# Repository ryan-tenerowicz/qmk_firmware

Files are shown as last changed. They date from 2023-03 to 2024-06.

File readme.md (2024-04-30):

# Lynxware Cat with trackpoint

https://www.lynxware.org/

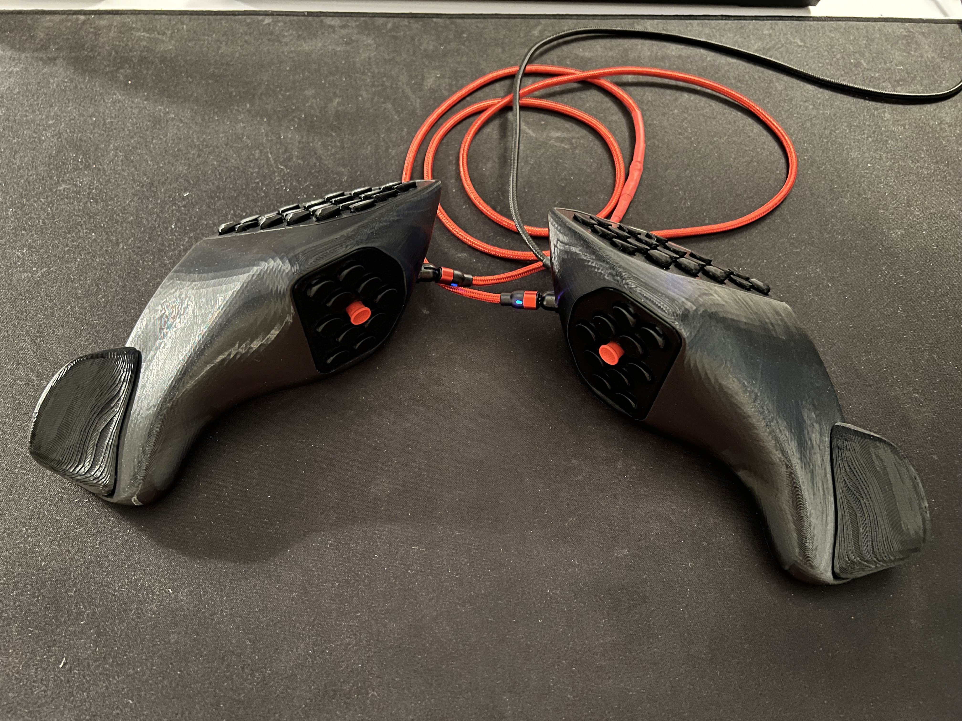
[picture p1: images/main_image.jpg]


I made some modifications to the case to work with the hardware I have. I already had some dual trackpoint code working in QMK so I made the connection wired and setup the matrix for qmk. I really like the magnetic usb cables so I carved out enough room for them. 

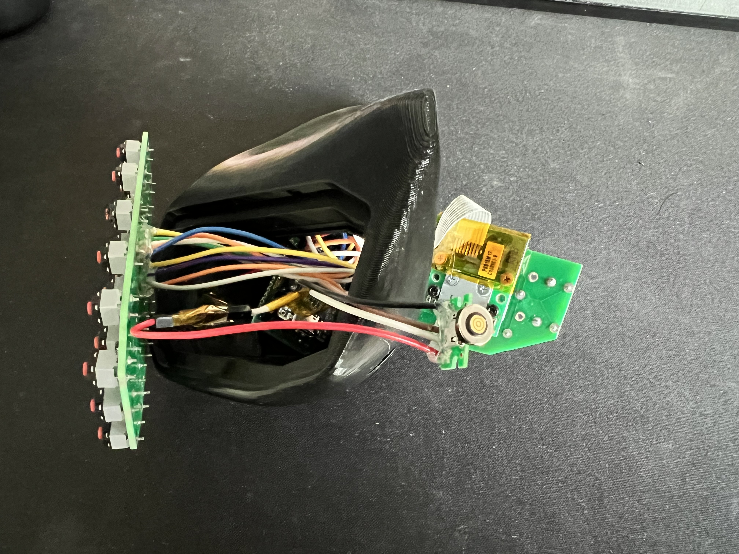
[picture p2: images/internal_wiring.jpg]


There's plenty of room on the inside so I was able to fit the reset circut easily.

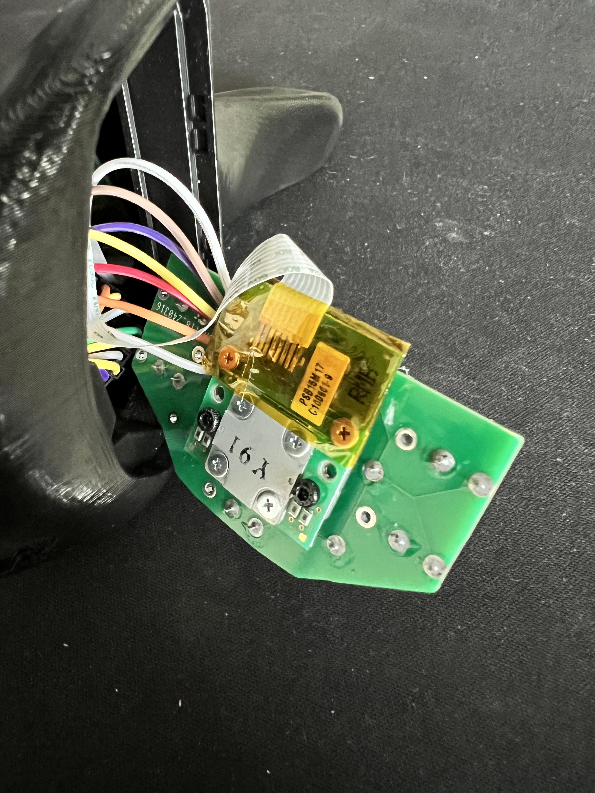
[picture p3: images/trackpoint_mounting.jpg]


I was able to get a much better surface finish on the keys by printing them at an angle. And I added wings to them to keep them from falling outwards because I was using smaller silent mouse switches.

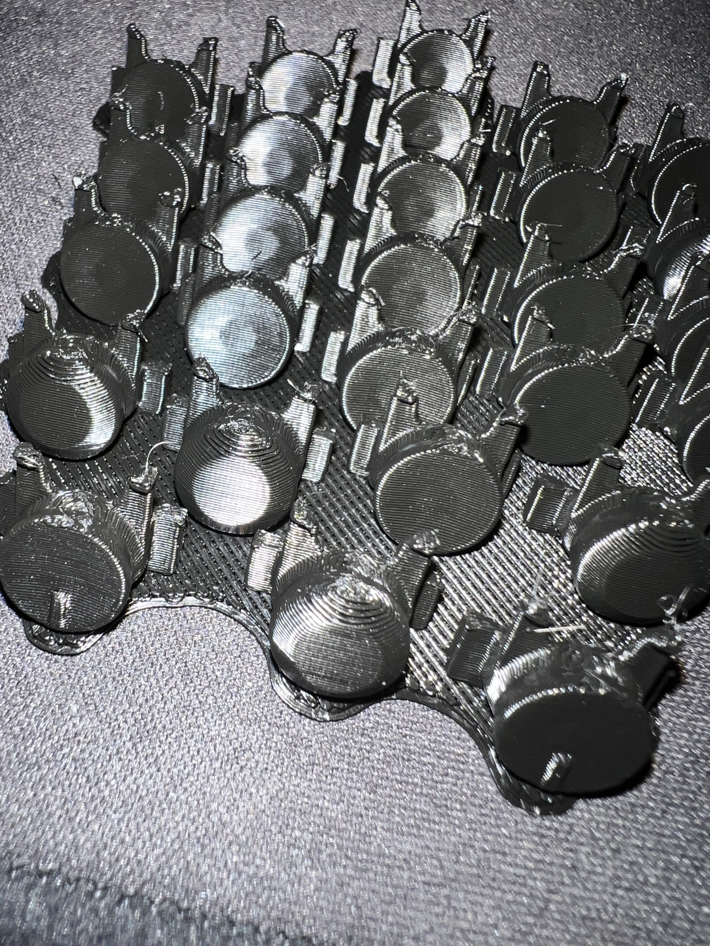
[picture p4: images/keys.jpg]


https://www.lynxware.org/

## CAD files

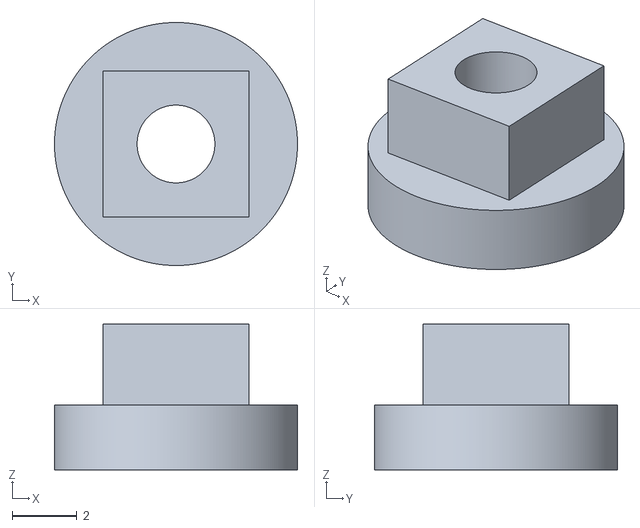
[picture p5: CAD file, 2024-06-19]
keyboards/rtenerowicz/rev2/cad/trackpoint top 4.stl
7.50 x 7.50 x 4.50

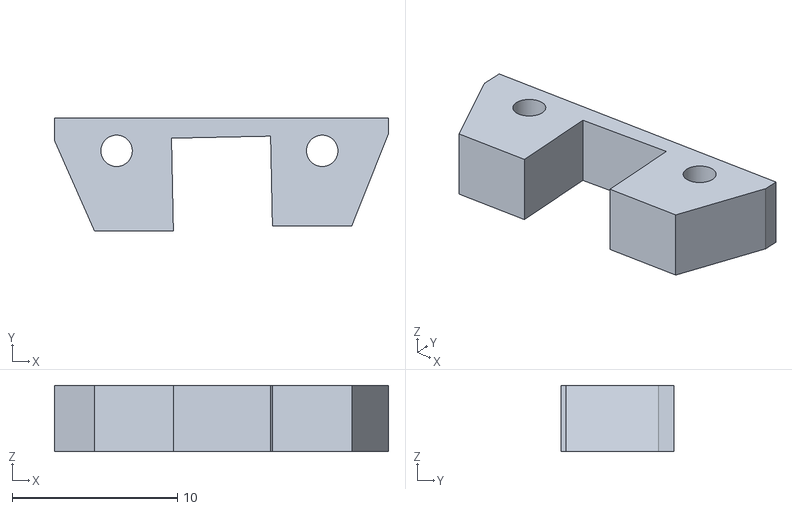
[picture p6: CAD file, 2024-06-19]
keyboards/rtenerowicz/rev2/cad/mouse riser.stl
20.2 x 6.87 x 4.00

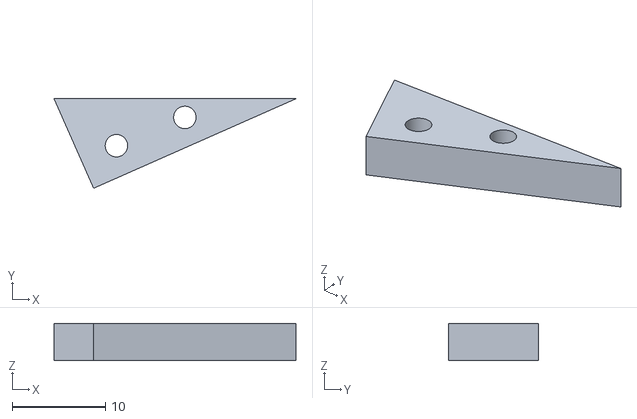
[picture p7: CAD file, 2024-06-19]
keyboards/rtenerowicz/rev2/cad/mouse together riser.stl
25.9 x 9.58 x 4.00

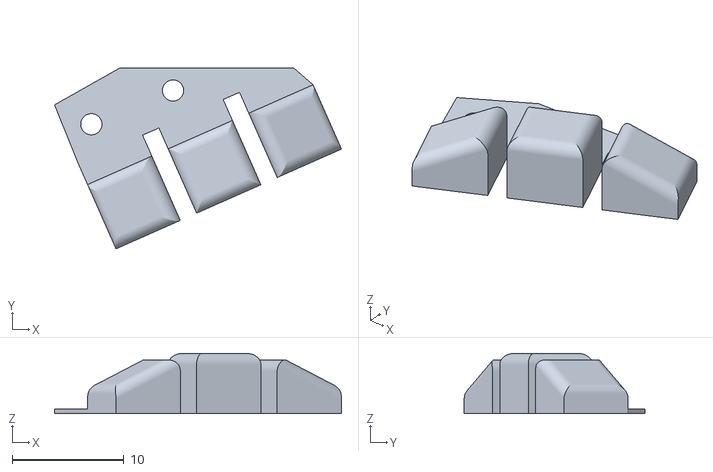
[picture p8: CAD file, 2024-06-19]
keyboards/rtenerowicz/rev2/cad/mouse buttons 5.stl
25.7 x 16.2 x 5.40

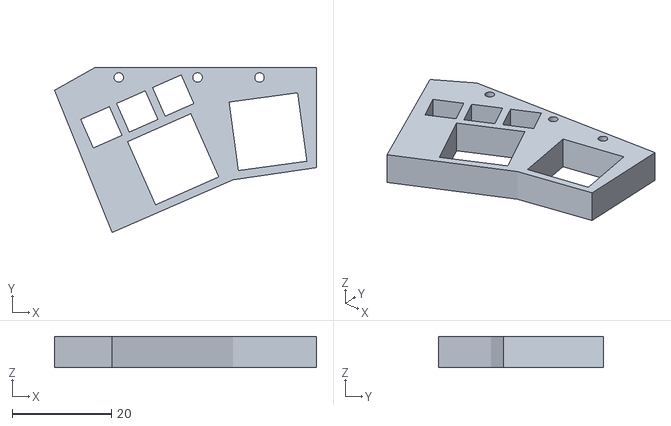
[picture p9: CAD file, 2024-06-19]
keyboards/rtenerowicz/rev2/cad/thumb_close.stl
52.7 x 33.2 x 6.30

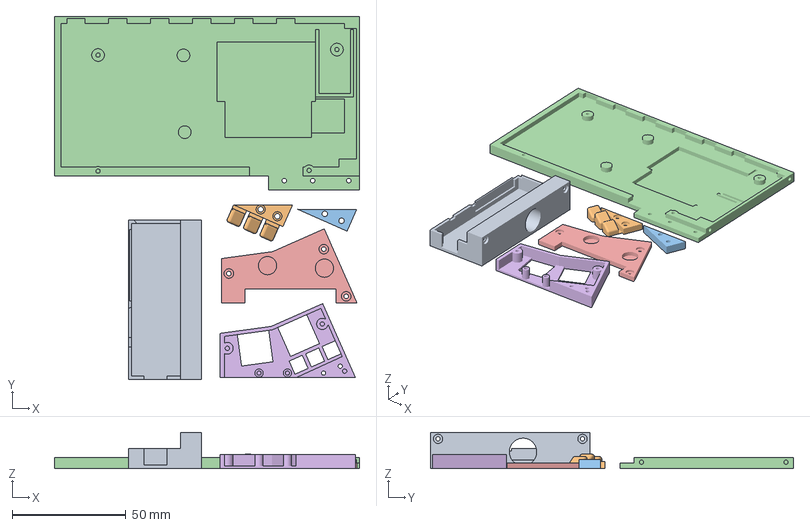
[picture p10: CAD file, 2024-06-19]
keyboards/rtenerowicz/rev2/cad/thumb together bottom.3mf
134.0 x 159.2 x 16.0 mm
cover.stl
mouse together buttons.stl
mouse together riser.stl
case thumb left.stl
thumb together bottom.stl
thumb together top.stl

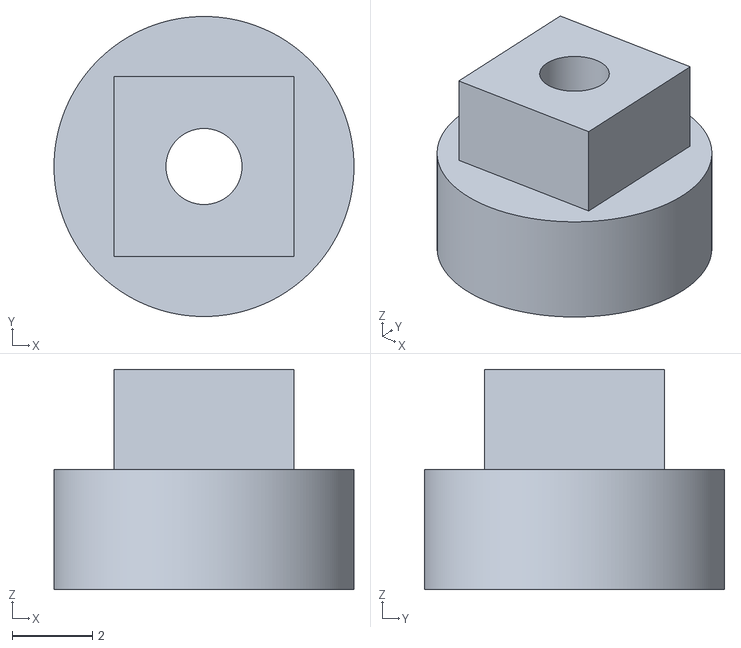
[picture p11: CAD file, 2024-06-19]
keyboards/rtenerowicz/rev2/cad/trackpoint top 3.stl
7.50 x 7.50 x 5.50

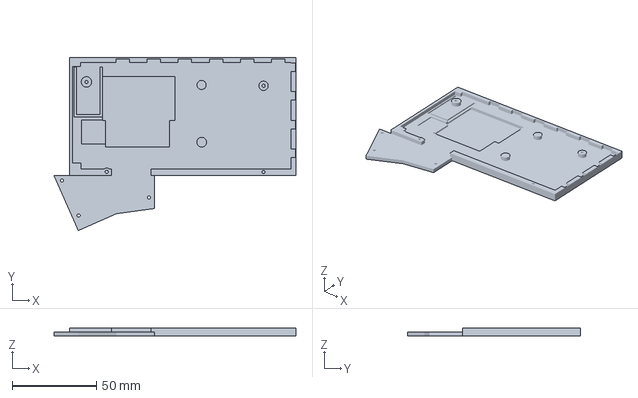
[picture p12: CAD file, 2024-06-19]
keyboards/rtenerowicz/rev2/cad/combined left.3mf
143.2 x 102.5 x 5.00 mm

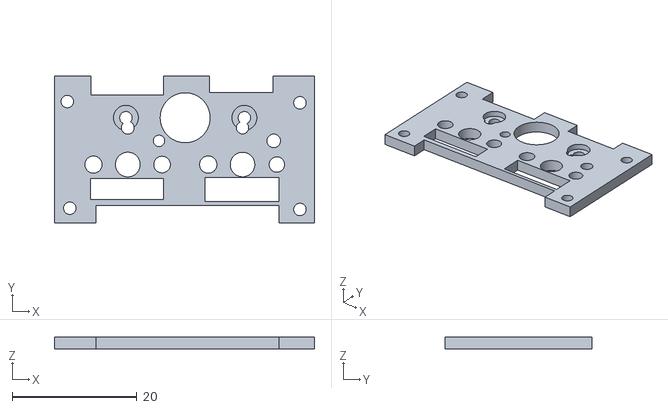
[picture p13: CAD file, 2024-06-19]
keyboards/rtenerowicz/rev2/cad/trackpoint right.stl
41.7 x 23.6 x 2.00

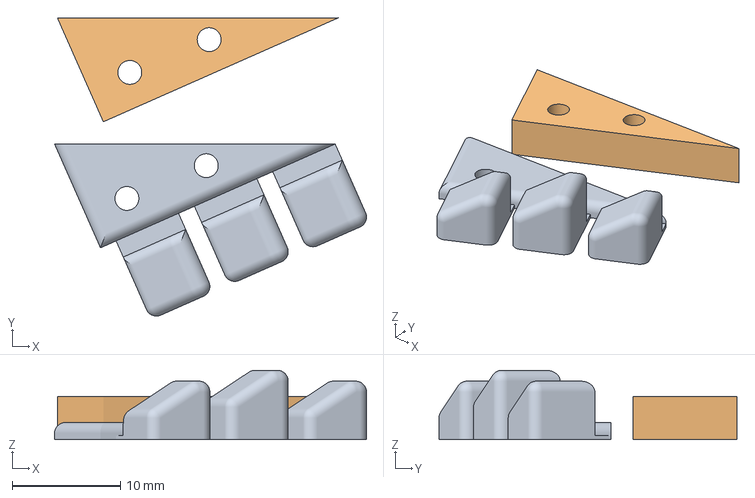
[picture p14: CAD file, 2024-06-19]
keyboards/rtenerowicz/rev2/cad/mouse together buttons.3mf
28.8 x 27.5 x 6.40 mm
mouse together buttons.stl
mouse together riser.stl

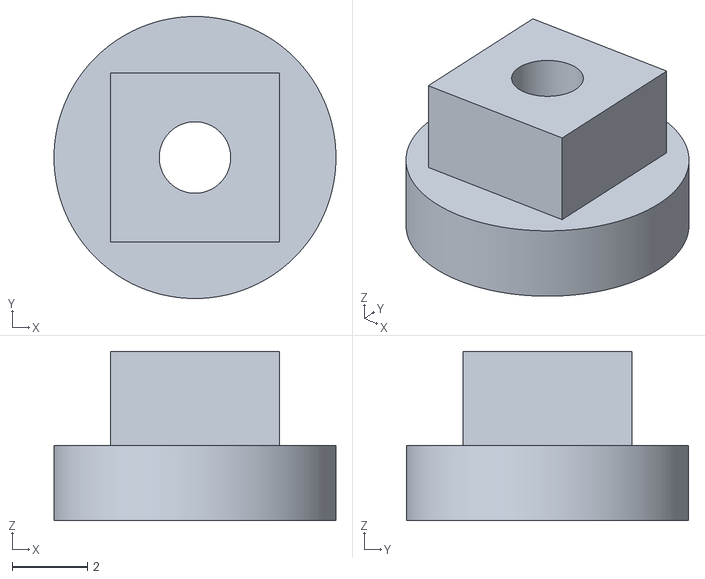
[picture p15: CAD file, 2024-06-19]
keyboards/rtenerowicz/rev2/cad/trackpoint top 2.stl
7.50 x 7.50 x 4.50

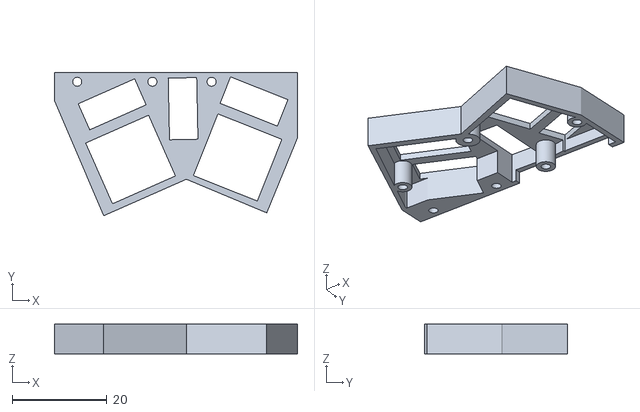
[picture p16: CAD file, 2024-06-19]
keyboards/rtenerowicz/rev2/cad/thumb_top.stl
51.2 x 30.2 x 6.30

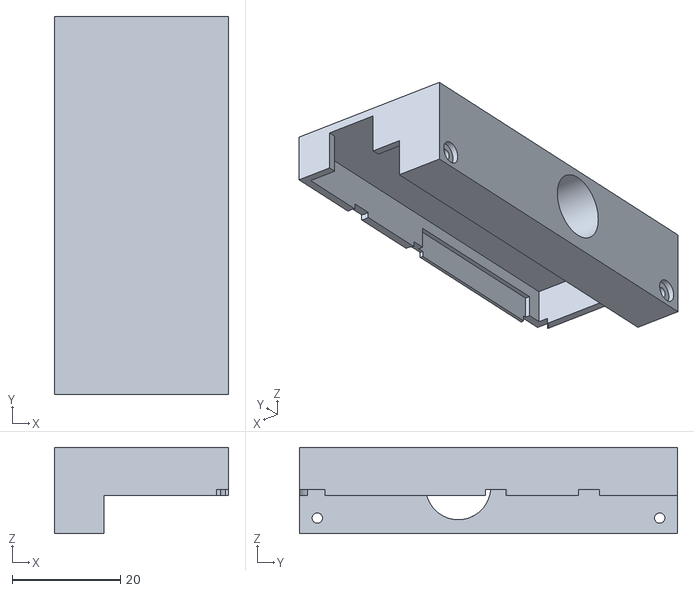
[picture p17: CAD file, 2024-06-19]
keyboards/rtenerowicz/rev2/cad/cover.stl
32.2 x 70.0 x 16.0

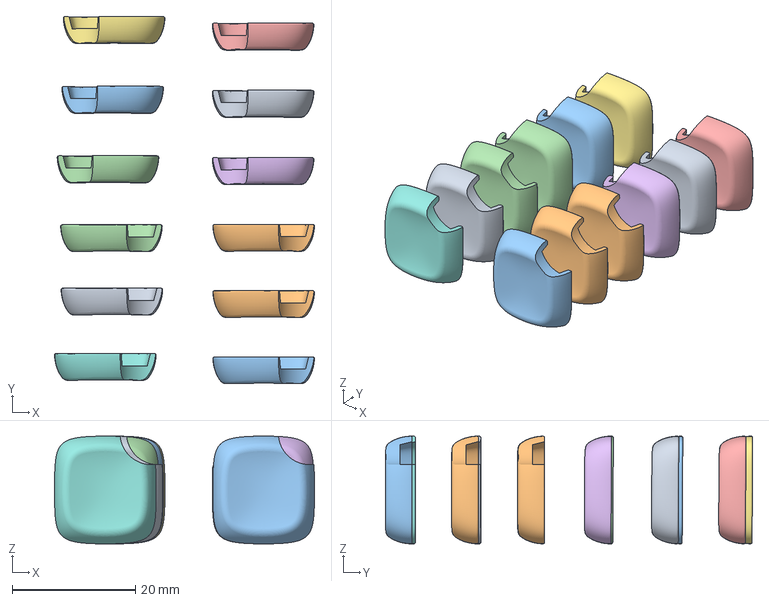
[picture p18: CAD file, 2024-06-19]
keyboards/rtenerowicz/rev2/cad/bottom left.3mf
42.2 x 59.6 x 17.5 mm
bottom left.stl x 6
bottom right.stl x 6

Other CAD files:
keyboards/rtenerowicz/rev2/cad/trackpoint top 1.stl
keyboards/rtenerowicz/rev2/cad/trackpoint top.stl
keyboards/rtenerowicz/rev2/cad/mouse buttons.stl
keyboards/rtenerowicz/rev2/cad/angle block.3mf
keyboards/rtenerowicz/rev2/cad/angle block.stl
keyboards/rtenerowicz/rev2/cad/case.stl
keyboards/rtenerowicz/rev2/cad/mouse buttons 6.3mf
keyboards/rtenerowicz/rev2/cad/mouse buttons 6.stl
keyboards/rtenerowicz/rev2/cad/thumb together bottom.stl
keyboards/rtenerowicz/rev2/cad/thumb together top.3mf
keyboards/rtenerowicz/rev2/cad/thumb together top.stl
keyboards/rtenerowicz/rev2/cad/thumb.stl
keyboards/rtenerowicz/rev2/cad/thumb_bottom.stl
keyboards/rtenerowicz/rev2/cad/trackpoint bottom.stl
keyboards/rtenerowicz/rev2/cad/trackpoint stick.stl
keyboards/rtenerowicz/rev2/cad/trackpoint top 5.stl

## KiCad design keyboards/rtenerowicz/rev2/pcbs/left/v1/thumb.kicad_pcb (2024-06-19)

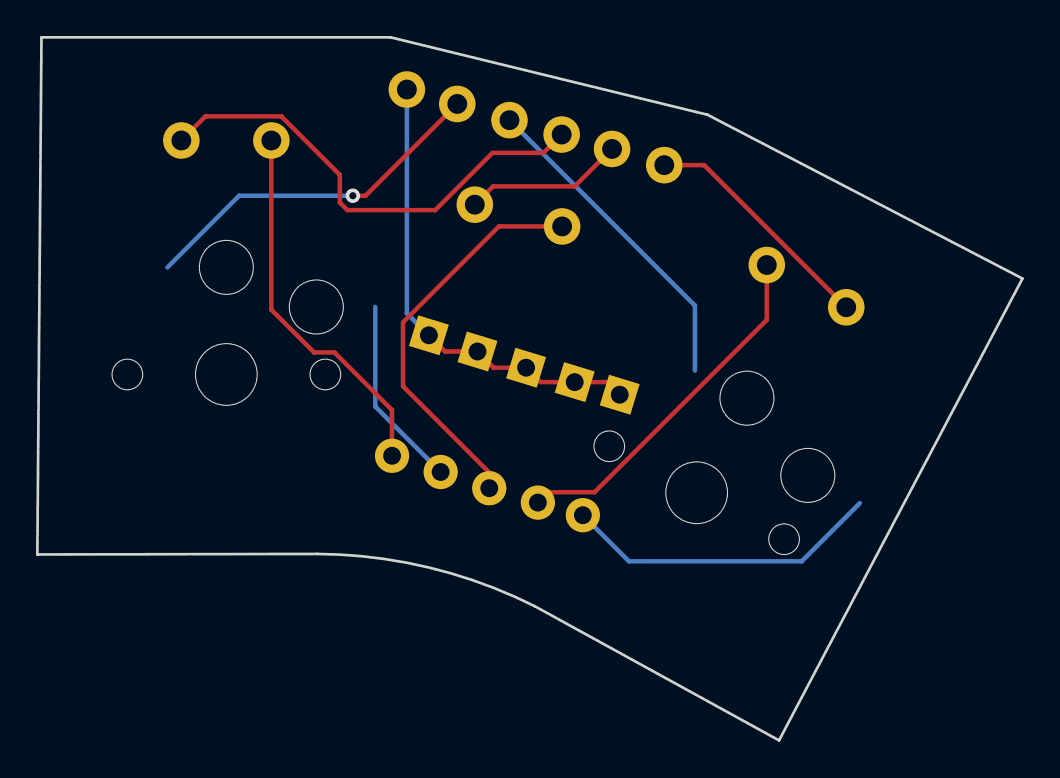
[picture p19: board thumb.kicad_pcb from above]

Board: 2 copper layers, 54.7 x 39.1 mm, 10 parts (0 on the bottom side), 6 nets.

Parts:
D3, D4, D5, D6, D7: ComboDiode
M1, M2, M3: kailhgm
S1, S2: PG1350

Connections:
F0: D3.2, D4.2, D5.2, D6.2, D7.2
far_thumb: D7.1, S2.2
inner_thumb: D4.1, S1.2
ml_diode: D3.1, M1.2
mm_diode: D6.1, M2.2
mr_diode: D5.1, M3.1

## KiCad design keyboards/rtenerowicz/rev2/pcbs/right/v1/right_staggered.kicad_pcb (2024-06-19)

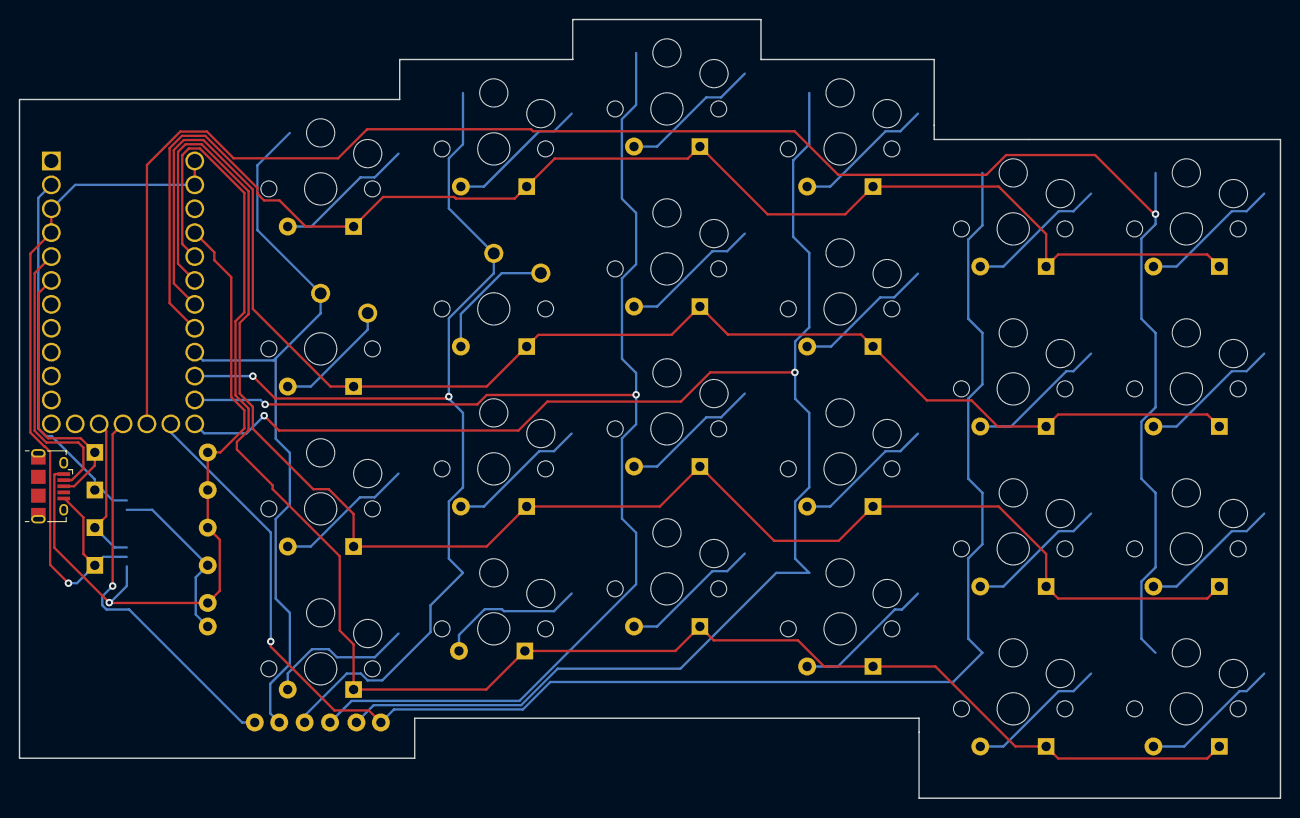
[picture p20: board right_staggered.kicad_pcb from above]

Board: 2 copper layers, 134.0 x 82.8 mm, 52 parts (0 on the bottom side), 35 nets.

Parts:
D1, D2, D3, D4, D5, D6, D7, D8, D9, D10, D11, D12, D13, D14, D15, D16, D17, D18, D19, D20, D21, D22, D23, D24, D25, D26, D27, D28: ComboDiode
S1, S2, S3, S4, S5, S6, S7, S8, S9, S10, S11, S12, S13, S14, S15, S16, S17, S18, S19, S20, S21, S22, S23, S24: PG1350

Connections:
B1: S1.2, S3.1, S4.1, S5.1
B2: S9.1, S10.1, S11.1, S12.1
B3: S2.2, S6.1, S7.1, S8.1
B6: S13.1, S14.1, S15.1, S16.1
F0: S17.1, S18.1, S19.1, S20.1
F1: S21.1, S22.1, S23.1, S24.1
F4: D1.2, D5.2, D9.2, D13.2, D17.2, D21.2
F5: D2.2, D6.2, D10.2, D14.2, D18.2, D22.2
F6: D3.2, D7.2, D11.2, D15.2, D19.2, D23.2
F7: D4.2, D8.2, D12.2, D16.2, D20.2, D24.2
VCC: D25.1, D26.1, D27.1
index_bottom: D5.1, S6.2
index_home: D6.1, S7.2
index_nums: D8.1, S8.2
index_top: D7.1, S2.1
inner_bottom: D1.1, S3.2
inner_home: D2.1, S4.2
inner_nums: D4.1, S5.2
inner_top: D3.1, S1.1
middle_bottom: D9.1, S9.2
middle_home: D10.1, S10.2
middle_nums: D12.1, S12.2
middle_top: D11.1, S11.2
outer_bottom: D21.1, S21.2
outer_home: D22.1, S22.2
outer_nums: D24.1, S24.2
outer_top: D23.1, S23.2
pinky_bottom: D17.1, S17.2
pinky_home: D18.1, S18.2
pinky_nums: D20.1, S20.2
pinky_top: D19.1, S19.2
ring_bottom: D13.1, S13.2
ring_home: D14.1, S14.2
ring_nums: D16.1, S16.2
ring_top: D15.1, S15.2

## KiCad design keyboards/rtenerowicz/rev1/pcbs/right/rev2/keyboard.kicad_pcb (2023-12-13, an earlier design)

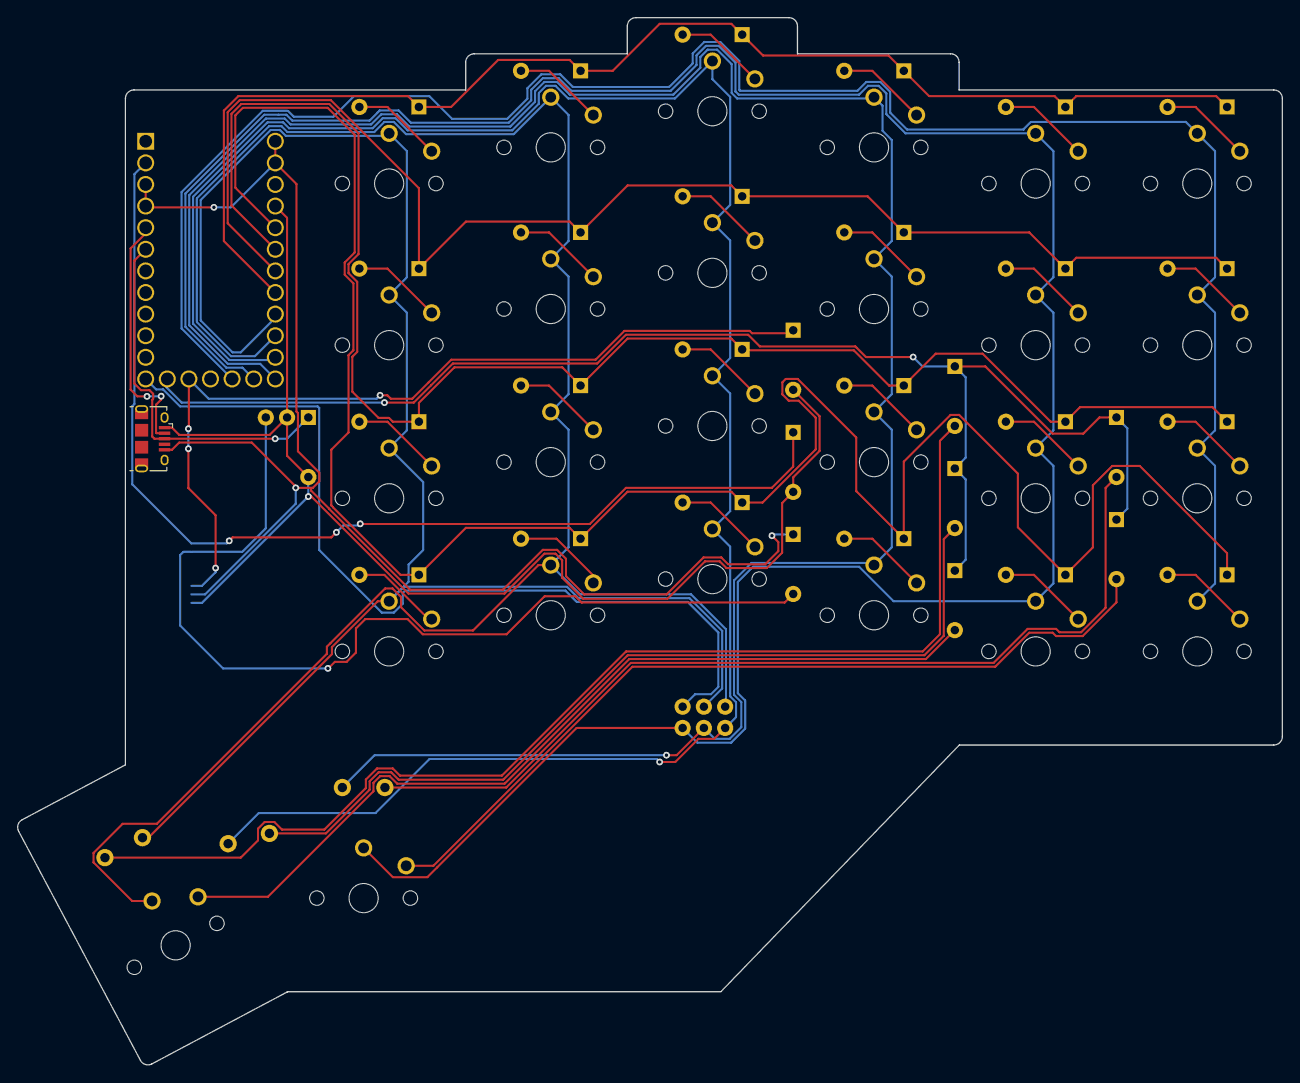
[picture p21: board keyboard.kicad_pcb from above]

Board: 2 copper layers, 148.7 x 123.1 mm, 63 parts (0 on the bottom side), 41 nets.

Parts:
D1, D2, D3, D4, D5, D6, D7, D8, D9, D10, D11, D12, D13, D14, D15, D16, D17, D18, D19, D20, D21, D22, D23, D24, D27, D28, D29, D30, D31, D32, D33, D34, D36: ComboDiode
D35: fiveway
M1, M2, M3: kailhgm
S1, S2, S3, S4, S5, S6, S7, S8, S9, S10, S11, S12, S13, S14, S15, S16, S17, S18, S19, S20, S21, S22, S23, S24, S25, S26: PG1350

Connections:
B1: D35.4, M3.2, S1.2, S2.2, S3.2, S4.2
B2: D35.2, M2.1, S9.2, S10.2, S11.2, S12.2
B3: D35.5, S5.2, S6.2, S7.2, S8.2, S26.2
B6: D35.1, M1.1, S13.2, S14.2, S15.2, S16.2
B7: D27.2, D28.2, D29.2, D30.2, D31.2
F0: D35.0, S17.2, S18.2, S19.2, S20.2, S25.2
F1: S21.2, S22.2, S23.2, S24.2
F4: D1.2, D5.2, D9.2, D13.2, D17.2, D21.2
F5: D2.2, D6.2, D10.2, D14.2, D18.2, D22.2
F6: D3.2, D7.2, D11.2, D15.2, D19.2, D23.2
F7: D4.2, D8.2, D12.2, D16.2, D20.2, D24.2
VCC: D33.1, D34.1, D36.1
far_thumb: D31.1, S26.1
index_bottom: D5.1, S5.1
index_home: D6.1, S6.1
index_nums: D8.1, S8.1
index_top: D7.1, S7.1
inner_bottom: D1.1, S1.1
inner_home: D2.1, S2.1
inner_nums: D4.1, S4.1
inner_thumb: D28.1, S25.1
inner_top: D3.1, S3.1
middle_bottom: D9.1, S9.1
middle_home: D10.1, S10.1
middle_nums: D12.1, S12.1
middle_top: D11.1, S11.1
ml_diode: D27.1, M1.2
mm_diode: D30.1, M2.2
mr_diode: D29.1, M3.1
outer_bottom: D21.1, S21.1
outer_home: D22.1, S22.1
outer_nums: D24.1, S24.1
outer_top: D23.1, S23.1
pinky_bottom: D17.1, S17.1
pinky_home: D18.1, S18.1
pinky_nums: D20.1, S20.1
pinky_top: D19.1, S19.1
ring_bottom: D13.1, S13.1
ring_home: D14.1, S14.1
ring_nums: D16.1, S16.1
ring_top: D15.1, S15.1

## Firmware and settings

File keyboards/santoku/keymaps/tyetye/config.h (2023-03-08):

/* Copyright 2021 Tye (@tyetye)
 *
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
 * You should have received a copy of the GNU General Public License
 * along with this program.  If not, see <http://www.gnu.org/licenses/>.
 */

#pragma once

// defines for unused feature (to save space)
#define NO_ACTION_ONESHOT
#undef LOCKING_SUPPORT_ENABLE
#undef LOCKING_RESYNC_ENABLE

// defines for combos feature (press two keys at one time to trigger an event)
#define COMBO_TERM  40  /* time limit in milliseconds combos need to be completed */	
#define COMBO_COUNT 8

// defines to help make home row mods more reliable
#define TAPPING_TOGGLE 2  /* How many times TT(__layer__) needs to be tapped to stick */
#define IGNORE_MOD_TAP_INTERRUPT
//#define TAPPING_FORCE_HOLD
//#define TAPPING_FORCE_HOLD_PER_KEY
#define TAPPING_TERM 200

// defines for making the Trackpoint more fluid
//#define PS2_MOUSE_USE_REMOTE_MODE

// defines for tuning the OLED
//#define OLED_SCROLL_TIMEOUT 50
#define OLED_TIMEOUT 10000
#define OLED_UPDATE_INTERVAL 100
#define OLED_FADE_OUT
#define OLED_FADE_OUT_INTERVAL 2

// defines for the CAPS_WORD feature
#define BOTH_SHIFTS_TURNS_ON_CAPS_WORD
#define CAPS_WORD_IDLE_TIMEOUT 5000

//#define HOLD_ON_OTHER_KEY_PRESS
//#define COMBO_ALLOW_ACTION_KEYS

// defines for the mouse scroll wheel (which probably don't work for the scroll wheel because it's based on clicks instead of holding the key down)
//#define MK_KINETIC_SPEED	
//#define MK_MOMENTARY_ACCEL
#define MOUSEKEY_DELAY	10	// Delay between pressing a movement key and cursor movement
#define MOUSEKEY_INTERVAL	20	// Time between cursor movements in milliseconds
#define MOUSEKEY_MOVE_DELTA	8	// Step size
#define MOUSEKEY_MAX_SPEED	10	// Maximum cursor speed at which acceleration stops
#define MOUSEKEY_TIME_TO_MAX	30	// Time until maximum cursor speed is reached
#define MOUSEKEY_WHEEL_DELAY	10	// Delay between pressing a wheel key and wheel movement
#define MOUSEKEY_WHEEL_INTERVAL	80	// Time between wheel movements
#define MOUSEKEY_WHEEL_MAX_SPEED	8	// Maximum number of scroll steps per scroll action
#define MOUSEKEY_WHEEL_TIME_TO_MAX	40	// Time until maximum scroll speed is reached

//#define WPM_LAUNCH_CONTROL    // https://docs.qmk.fm/#/feature_wpm?id=word-per-minute-wpm-calculcation

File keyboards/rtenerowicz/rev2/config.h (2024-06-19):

#define PS2_MOUSE_USE_REMOTE_MODE
#define PS2_CLOCK_PIN   D5
#define PS2_DATA_PIN    D2

#define PS2_USART_INIT() do {   \
    PS2_CLOCK_DDR &= ~(1<<PS2_CLOCK_BIT);   \
    PS2_DATA_DDR &= ~(1<<PS2_DATA_BIT);     \
    UCSR1C = ((1 << UMSEL10) |  \
              (3 << UPM10)   |  \
              (0 << USBS1)   |  \
              (3 << UCSZ10)  |  \
              (0 << UCPOL1));   \
    UCSR1A = 0;                 \
    UBRR1H = 0;                 \
    UBRR1L = 0;                 \
} while (0)
#define PS2_USART_RX_INT_ON() do {  \
    UCSR1B = ((1 << RXCIE1) |       \
              (1 << RXEN1));        \
} while (0)
#define PS2_USART_RX_POLL_ON() do { \
    UCSR1B = (1 << RXEN1);          \
} while (0)
#define PS2_USART_OFF() do {    \
    UCSR1C = 0;                 \
    UCSR1B &= ~((1 << RXEN1) |  \
                (1 << TXEN1));  \
} while (0)
#define PS2_USART_RX_READY      (UCSR1A & (1<<RXC1))
#define PS2_USART_RX_DATA       UDR1
#define PS2_USART_ERROR         (UCSR1A & ((1<<FE1) | (1<<DOR1) | (1<<UPE1)))
#define PS2_USART_RX_VECT       USART1_RX_vect

#define SPLIT_HAND_PIN B0
#define USE_I2C
#define SPLIT_MAX_CONNECTION_ERRORS 10
#define SPLIT_CONNECTION_CHECK_TIMEOUT 5000

#define SPLIT_POINTING_ENABLE
#define POINTING_DEVICE_COMBINED

#define MATRIX_COL_PINS_RIGHT { B1, B3, B2, B6, F0, F1 }
#define MATRIX_ROW_PINS_RIGHT { F7, F6, F5, F4, C7 }

#define TAPPING_TERM 500
#define TAPPING_TERM_PER_KEY
#define PERMISSIVE_HOLD
#define RETRO_TAPPING
#define QUICK_TAP_TERM 0

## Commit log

2023-03-08 gamelaster:ps2-pio PR merge (#22)
    * [Core] PS/2 PIO Driver for RP2040
    * Init pins in code instead of PIO
    * Use ChibiOS input buffer queue instead own ring buffer
    * Unify ps2_host_recv_response
    * Change ps2_host_send fifo check sequence + add forgotten sys unlock
    * Fix formatting
    * Add missing sys unlock from ISR
    * Ensure pio_rx_buffer is aligned for 32-bit access
    * Rework the PS/2 PIO driver as per PR #17893
    * Use pindirs to keep proper open drain behavior of PS/2.
    * Invert output enable on PS2_*_PIN so that pindirs works correctly with
    open-drain interface.
    * Enable autopull.
    * Disable sideset, as it's not used.
    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
2023-11-27 pointing device builds ps2 copy
2023-11-28 working driver
2023-12-06 left pcb
    [left-B_Cu.gbr, left-B_Mask.gbr, left-B_Paste.gbr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]
2023-12-13 pcb rev2
    [keyboard-B_Cu.gbr, keyboard-B_Mask.gbr, keyboard-B_Paste.gbr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]
2024-06-19 update
    update 2
    [angle block.3mf, angle block.stl, bottom left.3mf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]

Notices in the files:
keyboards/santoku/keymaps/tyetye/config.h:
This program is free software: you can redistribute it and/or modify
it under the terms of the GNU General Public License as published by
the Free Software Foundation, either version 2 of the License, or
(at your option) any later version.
